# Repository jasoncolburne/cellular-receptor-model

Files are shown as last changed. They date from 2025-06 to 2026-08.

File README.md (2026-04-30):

# cellular-receptor-model

An accessible (braille) openSCAD teaching model of a cellular receptor and its ligands,
suitable for 3d/FDM printing.

**I printed at a layer height of 0.20mm**

**I needed a single small support under the hole of the grey receptor.**

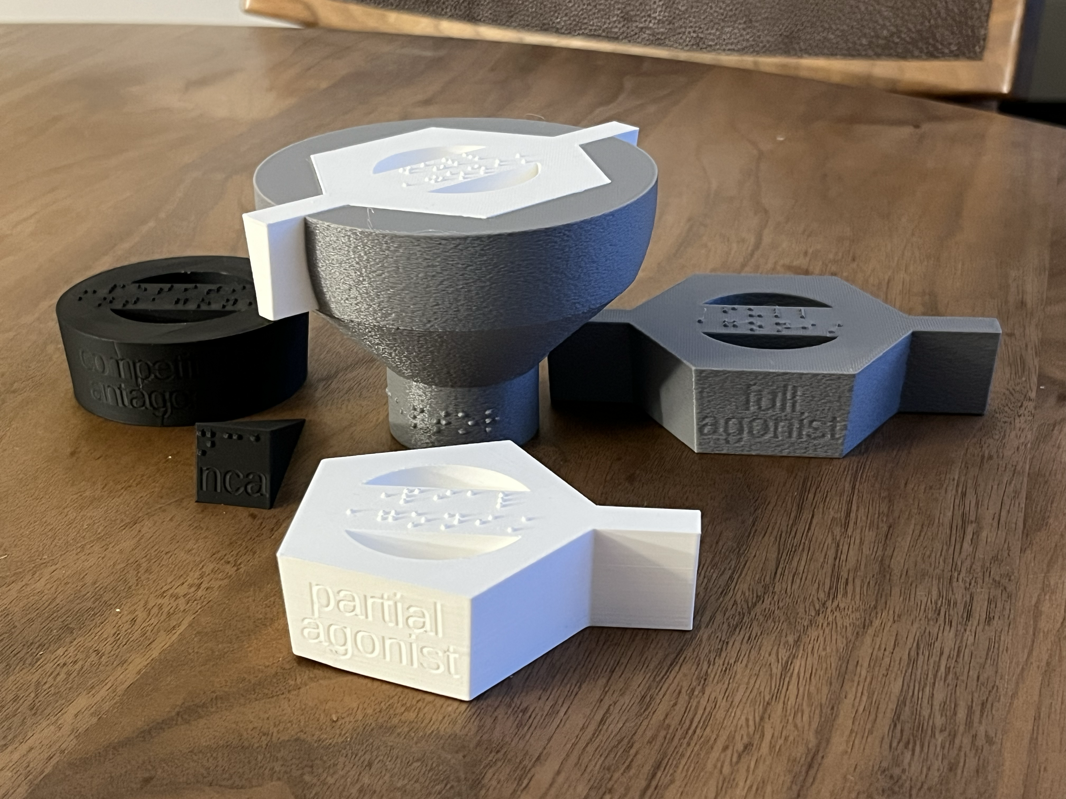
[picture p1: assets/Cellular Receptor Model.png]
Cellular Receptor Model


## Rationale

This was created to support an effort by Team Visual Assist at Dalhousie University (Canada). This
design was inspired by [the original](https://github.com/FilipKosel/3DDrugReceptor).

## Process

The model was prototyped in Bambu Studio on Bambu Lab A1/X2D FDM printers using stock settings and no AMS
(three plates/colors), after generating STL files using openSCAD. The filament used was Eureka PLA. There
is a 3mf file included in [./3mf/](./3mf/)

**Fuzzy Skin**: In the .3mf file, the endogenous models are printed using fuzzy skin. The two full agonist
models (exogenous and endogenous) are color matched and texture matched for accessibility.

### Braille

I tested various implementations and processes for printing the braille:

Implementations:
1. Spheres
2. Larger spheres
3. Larger spheres embedded deeper (smoothing attempt)
4. Cylinders with rounded tops

There wasn't a ton of difference in the jagged feel the top facing braille has. Braille on vertical
surfaces is far nicer, but the print doesn't really accomodate that for the three pieces containing
the most braille.

Processes:
1. Variable height layering (0.04mm (braille) -> 0.1mm (base) w/ 0.2mm nozzle)
2. Ironing

Ultimately, the results produced with the 0.2mm nozzle do not seem that much better than those
created with a 0.4mm nozzle. The print time is nearly 4x, so I would stick with the 0.4mm
and variable height layers. Ironing seemed to produce no appreciable effect, other than a better
finish.

## Learning Content

```
the cellular receptor is modeled with a space for ligands (molecules that bond to receptors).

the center space (marked below with an x) is a binding site for some ligands (agonists and
competitive antagonists of the receptor) to bond.

top view:
      ___
    _/   \_
    _  x  _    
     \___/

the slots on the side of the receptor can be thought of as (conceptual) activation points - when
both are filled, the receptor is fully activated, producing a maximal response. when one is filled,
this represents a partial state of activation that is somewhere between no response and the maximum.

top view:
      ___
    _/   \_
    _     _<- activation point
     \___/

the different ligands that bind to these sites produce varying effects, and they compete to
bond there.

the hole in the bottom represents a spot that a non-competitive antagonist may bond to.
like an off switch, it inhibits the activation of the receptor and cannot be overcome by
increasing available agonists. this is modeled by inserting the non-competitive agonist in
in the secondary bonding site, where it dislodges anything in the primary site. though the
mechanics of biology differ, the model provides a good analog.
 
the components of the kit demonstrate interactions with various ligands. 

full agonist - a molecule that bonds to the receptor and activates it with maximum efficacy.
  in our model, the full agonist is a hexagon that fills the receptor's primary binding site
  perfectly.

partial agonist - a molecule that bonds to the receptor and activates it with less than optimal
  efficacy. in our model, the partial agonist is a pentagon that fits in the hexagon shaped
  binding site, and activates a single activation point - representing a partial activation.

competitive antagonist - a molecule that bonds to the receptor and produces no effect, reducing
  the effect of agonists in the same system. in our model, the competitive antagonist is a circle
  that activates neither activation point.

non-competitive antagonist - a molecule that bonds to the receptor in an alternate location,
  inhibiting the receptor's action. in our model, the non-competitive antagonist is a tall,
  four-sided pyramid that is inserted through the exterior of the receptor.
```

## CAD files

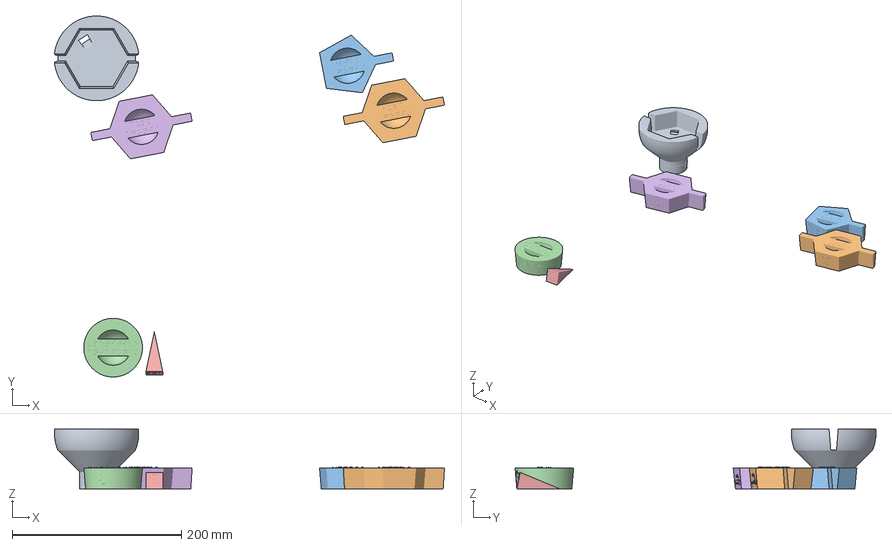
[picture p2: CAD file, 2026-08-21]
3mf/Accessible Cellular Receptor Learning Kit.3mf
460.5 x 426.2 x 70.8 mm
Receptor.stl
Full Agonist.stl
Partial Agonist.stl
Competitive Antagonist.stl
Non-Competitive Antagonist.stl
Endogenous Full Agonist.stl

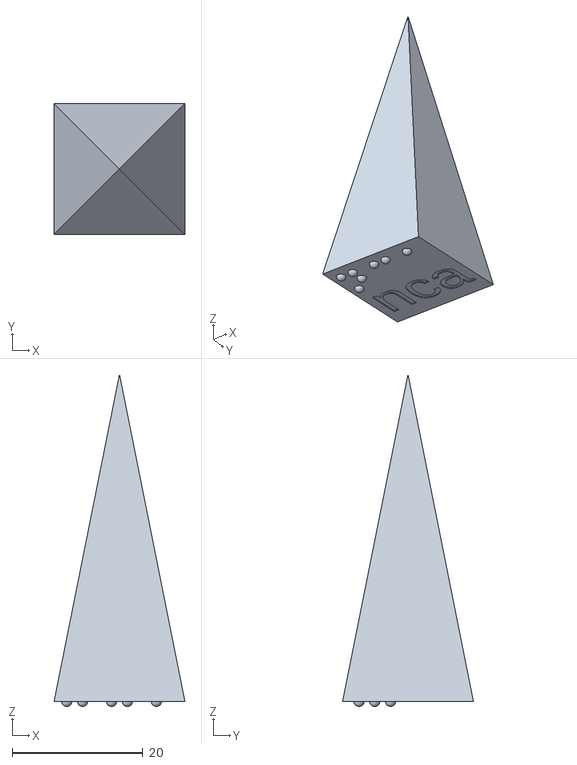
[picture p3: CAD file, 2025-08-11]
stl/Non-Competitive Antagonist.stl
20.0 x 20.0 x 50.8

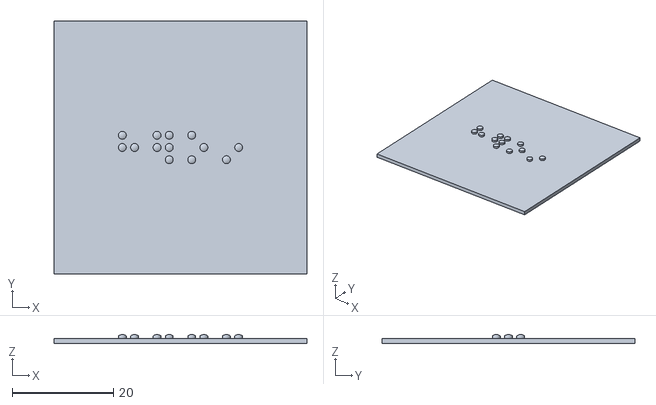
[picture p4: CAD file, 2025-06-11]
stl/test/braille-04-intersection.stl
50.0 x 50.0 x 1.75

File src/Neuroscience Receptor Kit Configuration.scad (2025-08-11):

// read receptor.scad

// parameters

receptor_radius = 50;
receptor_rim_height = 5;
receptor_rim_top_thickness = 10;
receptor_rim_bottom_thickness = receptor_rim_top_thickness + 2.5;
receptor_rim_cut_top_width = 10;
// this is a snowflake (all other values are multiples of 2.5)
receptor_rim_cut_bottom_width = receptor_rim_cut_top_width - 4.3;
receptor_rim_cut_depth = 25;

stabbing_pyramid_base_width = 20;
stabbing_pyramid_height = 50;

base_radius = 20;
base_height = 20;

resolution = 512;
tolerance = 1.01;

font_size = 8;
label_depth = 0.2;

$fn=resolution;

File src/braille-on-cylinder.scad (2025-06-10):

include <BOSL2/std.scad>;
include <brailleSCAD/en-us-g2.scad>;
include <brailleSCAD/braille.scad>;

module braille_on_cylinder(text,method="en-us-g2",size="small",style="sphere",radius,height,anchor,orient,spin)
{
  legal_styles = ["sphere"];
  legal_methods = ["en-us-g2"];
  dummy0 = assert(in_list(method, legal_methods), str("method must be one of ",legal_methods))
           assert(in_list(style,legal_styles), str(style,"style must be one of ",legal_styles));
  braille = method=="dots" ? text
          : method=="unicode" ? braille_unicode(text)
          : braille_transcribe(text);
  dummy=  assert(method!="dots" || is_list(text), "text must be a list of numbers or text strings with \"dots\" method")
          assert(in_list(size,["small","large"]),"size must be \"small\" or \"large\"");
  ind = size=="small" ? 0 : 1;
  attachable(anchor=anchor,orient=orient,spin=spin,
             size=[len(braille)*_braille_cell_sep[ind]*INCH, _braille_line_sep[ind]*INCH, _braille_height[ind]*INCH]){
    for(i=[0:1:len(braille)-1])
      let(symbol=braille[i])
      if (symbol && symbol!="0") // skip if zero or empty string (space)
          for(ch=str(symbol)){
            assert(len(search(ch,"123456"))>0, str("Got invalid digit, \"",ch, "\", in braille dots."));
            let(n=ord(ch)-ord("1"))
            let(text_width = (len(braille) - 1) * _braille_cell_sep[ind] * INCH)
            let(text_height = _braille_line_sep[ind]*INCH)
            let(local = _braille_dot_sep[ind] * INCH * [floor(n/3), -n%3])
            let(x_cell = i * _braille_cell_sep[ind] * INCH)
            let(x = local[0] + x_cell - text_width/2)
            let(y = local[1] + _braille_dot_sep[ind]*INCH + height/2)
            let(theta = 360 * x / (2 * PI * radius))
            let(x_cyl = radius * cos(theta))
            let(y_cyl = radius * sin(theta))
            let(z_cyl = y)
            translate([x_cyl, y_cyl, z_cyl])
                sphere(_braille_r[ind]*INCH);
    }  children();
  }
}

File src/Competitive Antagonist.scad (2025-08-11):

include <braille-on-flat.scad>;
include <Neuroscience Receptor Kit Configuration.scad>;
include <Primitives.scad>;

top_label = "competitive";
bottom_label = "antagonist";

top_widths = [for (i=[0:len(top_label)-1]) textmetrics(top_label[i], size=font_size).size[0]];
bottom_widths = [for (i=[0:len(bottom_label)-1]) textmetrics(bottom_label[i], size=font_size).size[0]];

top_offsets = make_offsets(top_widths, pad=0.2);
bottom_offsets = make_offsets(bottom_widths, pad=0.2);

module competitive_antagonist(bottom_radius, top_radius, height, resolution) {
    union() {
        difference() {
            translate([0,0,height/2])
                cylinder(h=height, r1=bottom_radius, r2=top_radius, $fn=resolution, center=true);

            text_on_cone(top_label, label_depth, top_widths, top_offsets, bottom_radius, top_radius, height, 0, 14);
            text_on_cone(bottom_label, label_depth, bottom_widths, bottom_offsets, bottom_radius, top_radius, height, 0, 5);
                
            translate([0,0,height])
                sphere(top_radius/1.666, $fn=resolution);
        }

        translate([0,0,height/2])
            cube([bottom_radius*1.5, 20, height], center=true);
            
        translate([0,0,height])
            back(_braille_line_sep[1]*INCH/2)
            braille_on_flat("competitive", $fn=50, size="large");

        translate([0,0,height])
            fwd(_braille_line_sep[1]*INCH/2)
            braille_on_flat("antagonist", $fn=50, size="large");
    }
}

top_radius = (receptor_radius-receptor_rim_top_thickness)*sqrt(3)/2;
bottom_radius = (receptor_radius-receptor_rim_bottom_thickness)*sqrt(3)/2;

competitive_antagonist(bottom_radius, top_radius, receptor_rim_cut_depth, resolution);

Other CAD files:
src/braille-on-flat.scad
src/Full Agonist.scad
src/Non-Competitive Antagonist.scad
src/Partial Agonist.scad
src/Primitives.scad
src/Receptor.scad
src/braille-test.scad

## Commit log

2025-06-10 Build out kit (#1)
    [Competitive Antagonist.scad, Full Agonist.scad, Neuroscience Receptor Kit Configuration.scad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]
2025-06-10 fix braille (#3)
    [Competitive Antagonist.scad, Full Agonist.scad, Non-Competitive Antagonist.scad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]
2025-06-11 more (#4)
    [Competitive Antagonist.scad, Full Agonist.scad, Neuroscience Receptor Kit Configuration.scad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]
2025-06-11 smoothing (#7)
    [Competitive Antagonist.scad, Full Agonist.scad, Partial Agonist.scad]
2025-08-11 add text (#10)
    [Competitive Antagonist.scad, Full Agonist.scad, Neuroscience Receptor Kit Configuration.scad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]
2026-04-30 tolerance for fuzzy skin
    [Neuroscience Receptor Kit Configuration.scad]
2026-05-16 tweak fit, improve 3mf
    [Accessible Cellular Receptor Learning Kit.3mf, Neuroscience Receptor Kit Configuration.scad]
2026-05-17 improve tolerance for fuzzy skin
    [Accessible Cellular Receptor Learning Kit.3mf, Receptor.scad]
2026-05-18 endorgenous -> endogenous
    [Accessible Cellular Receptor Learning Kit.3mf]
2026-06-11 Update studio authoring version
    [Accessible Cellular Receptor Learning Kit.3mf]
2026-08-21 Refine tolerance for fuzzy skin on X2D
    [Accessible Cellular Receptor Learning Kit.3mf, Receptor.scad]
